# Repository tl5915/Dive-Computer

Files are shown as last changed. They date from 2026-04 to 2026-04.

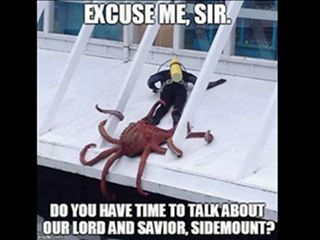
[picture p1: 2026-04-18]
Startup_Image/image.png

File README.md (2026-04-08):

# Dive Computer

Based on the previous [bottom timer project]([https://](https://github.com/tl5915/Bottom-Timer-for-DPV)). Pressure sensor and housing remains the same.

- Add dive computer mode with Bühlmann ZHL-16C algorithm
- Add tilt compensated digital compass with soft and hard iron calibration
- Backlight auto adjustment

## Hardware

- Change MCU from ESP32-C3 to ESP32-S3 (Waveshare ESP32-S3-LCD-1.69)
- Change display from 1.54 inch OLED to 1.69 inch IPS LCD
- Onboard QMI8658 6-axis IMU
- Offboard QMC5883L magnetometer
- Offboard BH1750 light sensor

## Software

- Press onboard button to start compass calibration, rotate in all directions in 60 seconds
- Dive timer start at 1m depth
- Default bottom timer view with digital compass
- Triple tap to switch to dive computer mode:
  
  | Stop | Time | TTS | surfGF |
- In dive computer mode, double tap to change gradient factor to `100/100`

### Decompression model assumptions

- Fixed gradient factor `60/85` (optional overide)
- Close circuit with fixed set point of `1.2`
- Ascent rate 9 m/min
- Sea level 1 atm
- No prior dives
- No helium penalty

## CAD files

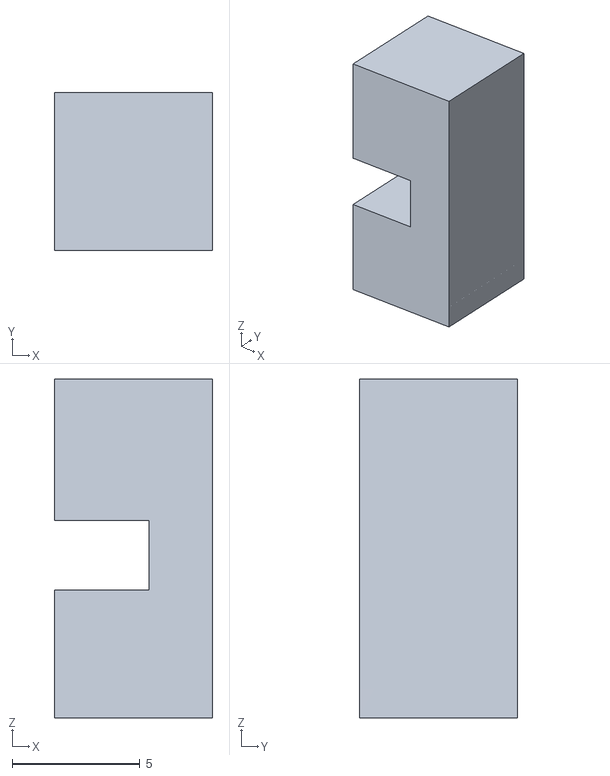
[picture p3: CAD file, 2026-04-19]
STL/Button.stl
6.20 x 6.20 x 13.3

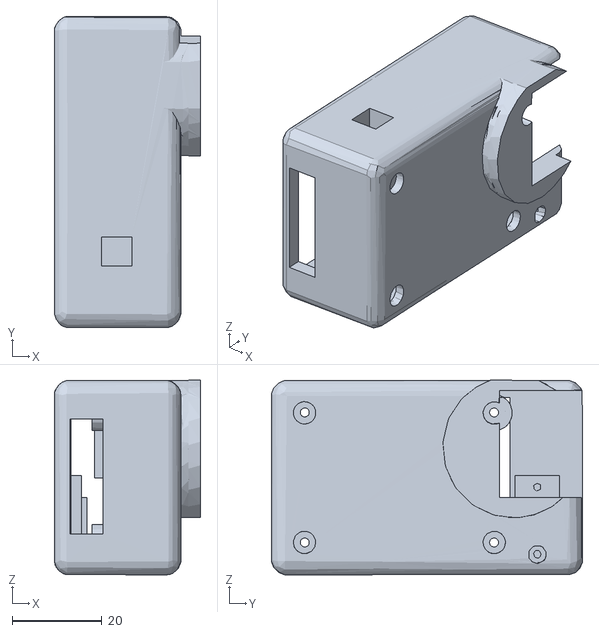
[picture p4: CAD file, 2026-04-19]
STL/Insert_2.stl
32.6 x 69.4 x 43.4

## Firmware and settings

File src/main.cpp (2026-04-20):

#include <Arduino.h>
// Power Management
#include <esp_pm.h>
#include <esp_bt.h>
#include <esp_wifi.h>
#include <esp_sleep.h>
#include <esp_heap_caps.h>
#include <driver/rtc_io.h>
// Peripherals
#include <SPI.h>
#include <Wire.h>
#include <BH1750.h>
#include <MS5837.h>
#include <Adafruit_GFX.h>
#include <Adafruit_ST7789.h>
#include <SensorQMI8658.hpp>
#include <SensorQMC5883P.hpp>
// Data Processing
#include <vector>
#include <WiFi.h>
#include <ZHL16C.h>
#include <SPIFFS.h>
#include <pgmspace.h>
#include <WebServer.h>
#include <Preferences.h>
#include <TJpg_Decoder.h>
#include <Adafruit_AHRS.h>
#include <magnetometer_calibration.h>
// Header Files
#include "demo.h"
#include "image.h"
#include "compass_label.h"

// Pin Definitions
// System
constexpr uint8_t RST_Pin = 0;  // Boot button/ LCD reset
constexpr uint8_t Battery_Pin = 5;  // Battery ADC
// Button
constexpr uint8_t Button_Pin = 9;  // Connect to GND
// I2C
constexpr uint8_t IMU_INT_Pin = 3;  // Internal
constexpr uint8_t QMC_DRDY_Pin = 11;
constexpr uint8_t GND_Pin = 13;  // Grounded
constexpr uint8_t VCC_Pin = 15;
constexpr uint8_t SCL_Pin = 47;  // Fixed
constexpr uint8_t SDA_Pin = 48;  // Fixed
// LCD (internal)
constexpr uint8_t Backlight_Pin = 1;
constexpr uint8_t MOSI_Pin = 38;
constexpr uint8_t SCK_Pin = 39;
constexpr uint8_t MISO_Pin = 40;
constexpr uint8_t SD_CS_Pin = 41;  // SD card CS
constexpr uint8_t DC_Pin = 42;
constexpr uint8_t LCD_CS_Pin = 45;  // LCD CS

// Objects
SPIClass spi(FSPI);
Adafruit_ST7789 display(&spi, LCD_CS_Pin, DC_Pin, RST_Pin);
Preferences prefs;
MS5837 sensor;
BH1750 lightMeter;
SensorQMI8658 qmi;
SensorQMC5883P qmc;
Adafruit_Madgwick ahrs;

// I2C Addresses
constexpr uint8_t QMI8658_I2C_Address = 0x6B;
constexpr uint8_t QMC5883P_I2C_Address = 0x2C;
constexpr uint8_t BH1750_I2C_Address = 0x23;
constexpr uint8_t MS5837_I2C_Address = 0x76;

// LCD Constants
constexpr uint16_t LCD_Width = 320;
constexpr uint16_t LCD_Height = 240;
constexpr uint8_t Low_Battery_Threshold = 10;      // Dim screen at 10%
constexpr uint8_t Critical_Battery_Threshold = 0;  // Auto shut down at 0%
constexpr float Battery_Divider_Ratio = 3.0f;      // 2:1 voltage divider
constexpr float Ambient_Lux_Max = 40000.0f;        // Lux at high backlight
constexpr uint8_t Backlight_Low = 8;               // Low backlight
constexpr uint8_t Backlight_High = 255;            // High backlight
constexpr uint32_t Message_MS = 3000;              // Display messages for 3 seconds
constexpr uint32_t Display_Update_MS = 50;         // Display refresh rate: 20 Hz
constexpr uint32_t Depth_Update_MS = 500;          // Depth sensor and ADC updates: 2 Hz
constexpr uint32_t Deco_Update_MS = 5000;          // Decompression model updates: 0.2 Hz

// Button Constants
constexpr uint32_t Button_Long_MS = 800;          // Long press threshold
constexpr uint32_t Button_Hold_MS = 5000;         // Press and hold threshold
constexpr uint32_t Calibration_Delay_MS = 10000;  // Delay before calibration

// Depth Sensor Constants
constexpr uint16_t Density = 1020;        // EN13319 density
constexpr float MBAR_PER_ATM = 1013.25f;  // mBar per atm
constexpr float Depth_Offset = 0.2f;      // Sea level offset 0.2 m
constexpr float Dive_Start_Depth = 1.0f;  // Start timer at 1 m

// ZHL-16C Constants
constexpr uint8_t GF_Low = 60;    // Gradient factor low
constexpr uint8_t GF_High = 85;   // Gradient factor high
constexpr float Setpoint = 1.2f;  // CCR setpoint

// IMU Offset Constants
constexpr float Accel_Offset_X = 0.0;
constexpr float Accel_Offset_Y = 0.0f;
constexpr float Accel_Offset_Z = 0.0f;
constexpr float Gyro_Offset_X = 0.4791f;
constexpr float Gyro_Offset_Y = 5.7993f;
constexpr float Gyro_Offset_Z = -0.7015f;

// Compass Constants
constexpr float Compass_Offset = 0.0;                        // Compass offset degrees
constexpr float Reference_Field_Gauss = 0.49f;               // UK average magnetic field strength
constexpr float Magnetometer_Lsb_Per_Gauss = 3750.0f;        // QMC5883P at FS_8G: 3750 LSB/Gauss
constexpr uint32_t Compass_Calibration_Duration_MS = 30000;  // 30 seconds for compass calibration
constexpr const char *Compass_NVS_Namespace = "compass";
constexpr const char *Calibration_Valid_Key = "cal_valid";
constexpr const char *Hard_Iron_X_Key = "hi_x";
constexpr const char *Hard_Iron_Y_Key = "hi_y";
constexpr const char *Hard_Iron_Z_Key = "hi_z";
constexpr const char *Soft_Iron_Key = "soft_iron";
constexpr const char *Reference_Mag_Gauss_Key = "ref_gauss";
constexpr const char *Lsb_Per_Gauss_Key = "lsb_gauss";
constexpr const char *Fitted_Field_Lsb_Key = "fit_lsb";
constexpr const char *Settings_NVS_Namespace = "settings";
constexpr const char *Demo_Mode_Key = "demo_mode";

// Default Compass Calibration Matrix
constexpr CompassCalibrationMatrices Default_Compass_Matrices = {
  .hard_iron = {431.913489, 296.874488, 374.476474},
  .soft_iron = {
    0.000330f, 0.000001f, -0.000020f,
    0.000001f, 0.000308f, 0.000008f,
    -0.000020f, 0.000008f, 0.000300f
  },
  .reference_field_gauss = Reference_Field_Gauss,
  .lsb_per_gauss = Magnetometer_Lsb_Per_Gauss,
  .fitted_field_lsb = Reference_Field_Gauss * Magnetometer_Lsb_Per_Gauss,
  .is_valid = true
};

// Battery Percentage Lookup Table
constexpr float Voltage_Table[] = {
    3.27f, 3.61f, 3.69f, 3.71f, 3.73f, 3.75f, 3.77f, 3.79f, 3.80f, 3.82f, 3.84f, 3.85f, 3.87f, 3.91f, 3.95f, 3.98f, 4.02f, 4.08f, 4.11f, 4.15f, 4.20f};
constexpr uint8_t Percentage_Table[] = {
    0, 5, 10, 15, 20, 25, 30, 35, 40, 45, 50, 55, 60, 65, 70, 75, 80, 85, 90, 95, 100};
constexpr size_t Battery_Table_Size = sizeof(Voltage_Table) / sizeof(Voltage_Table[0]);

// SPIFFS JPEG path
constexpr const char *Spiffs_Jpeg_Path = "/image.jpg";

// WiFi AP credentials
constexpr const char *SSID = "DiveComputer";
constexpr const char *Password = "12345678";

// RTOS Variables
TaskHandle_t Display_Task_Handle = nullptr;
TaskHandle_t Sensor_Task_Handle = nullptr;
TaskHandle_t Image_Task_Handle = nullptr;
GFXcanvas16 *Frame_Canvas = nullptr;
uint16_t *Frame_Back_Previous = nullptr;
uint16_t *Frame_Back_Current = nullptr;
uint16_t Render_Width = 0;
uint16_t Render_Height = 0;
size_t Frame_Buffer_Bytes = 0;
bool Frame_Have_Previous = false;
bool Spiffs_Jpeg_Ready = false;

// Modes
bool Demo_Mode = false;
bool ripNtear_Mode = false;

// Dive Variables
float Heading = 0.0f;
float Depth = 0.0f;
int Minutes = 0;
int Seconds = 0;
int Stopwatch_Minutes = 0;
int Stopwatch_Seconds = 0;
uint64_t Timer_Start_MS = 0;
uint64_t Stopwatch_Start_MS = 0;
uint64_t Simulated_Profile_Start_MS = 0;
bool Dive_Timer_Started = false;
bool Stopwatch_Active = false;
bool sensorAvailable = false;

// Battery Variables
float Ambient_Lux = 0.0f;
float Battery_Voltage = 0.0f;
uint8_t Battery_Percentage = 0;
uint8_t Backlight_Level = Backlight_High;

// Press Button Variables
uint8_t Button_Consecutive_Reads = 0;
uint8_t Button_Last_Reading = HIGH;
uint8_t Button_Stable_State = HIGH;
uint64_t Button_Last_Change_MS = 0;
uint64_t Button_Press_Start_MS = 0;
bool Button_Long_Event_Fired = false;
bool Button_Hold_Event_Fired = false;

// Boot Button Variables
uint8_t Boot_Consecutive_Reads = 0;
uint8_t Boot_Last_Reading = HIGH;
uint8_t Boot_Stable_State = HIGH;
uint64_t Boot_Last_Change_MS = 0;
uint64_t Boot_Press_Start_MS = 0;
bool Boot_Long_Event_Fired = false;
bool Boot_Hold_Event_Fired = false;

// Decompression Variables
DecoResult lastDecoResult = {false, 0, 0, 0, 0};
uint64_t Deco_Last_Update_MS = 0;

// Compass Labels
float projectCompassX3D(float x, float centerX, float width) {
  constexpr float Projection_Exponent = 2.1f;
  if (x <= centerX) {
    const float t = constrain(x / centerX, 0.0f, 1.0f);
    return powf(t, Projection_Exponent) * centerX;
  }
  const float rightSpan = width - centerX;
  const float t = constrain((width - x) / rightSpan, 0.0f, 1.0f);
  return (centerX - (powf(t, Projection_Exponent) * centerX)) + centerX;
}
float smoothstep01(float t) {
  t = constrain(t, 0.0f, 1.0f);
  return t * t * (3.0f - (2.0f * t));
}
float compassCenterWeight(float projectedX, float centerX) {
  const float maxDist = centerX;
  const float dist = fabsf(projectedX - centerX);
  const float linearWeight = 1.0f - constrain(dist / maxDist, 0.0f, 1.0f);
  return smoothstep01(linearWeight);
}
void drawScaledXBitmap(Adafruit_GFX &target, int16_t x, int16_t y, uint8_t srcW, uint8_t srcH, const uint8_t *bitmap, float scale, uint16_t color) {
  if (bitmap == nullptr || scale <= 0.0f) return;
  const int16_t dstW = static_cast<int16_t>(srcW * scale + 0.5f);
  const int16_t dstH = static_cast<int16_t>(srcH * scale + 0.5f);
  if (dstW <= 0 || dstH <= 0) return;
  const uint8_t bytesPerRow = static_cast<uint8_t>((srcW + 7) / 8);
  for (int16_t dy = 0; dy < dstH; ++dy) {
    const uint8_t sy = static_cast<uint8_t>((static_cast<int32_t>(dy) * srcH) / dstH);
    for (int16_t dx = 0; dx < dstW; ++dx) {
      const uint8_t sx = static_cast<uint8_t>((static_cast<int32_t>(dx) * srcW) / dstW);
      const uint16_t byteIndex = static_cast<uint16_t>(sy * bytesPerRow + (sx / 8));
      const uint8_t rowByte = pgm_read_byte(bitmap + byteIndex);
      const bool isSet = (rowByte & (1U << (sx & 7))) != 0;
      if (isSet) target.drawPixel(x + dx, y + dy, color);
    }
  }
}

// Compass Calibration Method and Quality
CompassCalibrationMatrices Compass_Matrices = {};
enum class CompassCalibrationMethod : uint8_t {
  None = 0,
  Ellipsoid = 1,
  MinMax = 2,
  Error = 3,
};
CompassCalibrationMethod Last_Calibration_Method = CompassCalibrationMethod::None;
static const char* compassCalibrationMethodText(CompassCalibrationMethod method) {
  switch (method) {
    case CompassCalibrationMethod::Ellipsoid: return "Ellipsoid";
    case CompassCalibrationMethod::MinMax: return "Min/Max";
    case CompassCalibrationMethod::Error: return "Error";
    case CompassCalibrationMethod::None:
    default: return "None";
  }
}
CompassCalibrationQuality Last_Calibration_Quality = {};
enum class CalibrationFailReason : uint8_t {
  None = 0,
  TooFewSamples,
  FitFailed,
  ApplyFailed,
  InvalidQuality,
};
CalibrationFailReason Last_Calibration_Fail_Reason = CalibrationFailReason::None;
size_t Last_Calibration_Sample_Count = 0;
uint32_t Last_Calibration_Elapsed_MS = 0;
static const char* calibrationFailReasonText(CalibrationFailReason reason) {
  switch (reason) {
    case CalibrationFailReason::TooFewSamples: return "Too few samples";
    case CalibrationFailReason::FitFailed: return "Fit failed";
    case CalibrationFailReason::ApplyFailed: return "Apply failed";
    case CalibrationFailReason::InvalidQuality: return "Invalid quality";
    case CalibrationFailReason::None:
    default: return "None";
  }
}

// Press Button State
enum class PressButtonEvent : uint8_t {
  None = 0,
  ShortPress,
  LongPress,
  HoldPress,
};
PressButtonEvent checkButton(uint64_t nowMS) {
  const uint8_t reading = static_cast<uint8_t>(digitalRead(Button_Pin));
  PressButtonEvent event = PressButtonEvent::None;
  if (reading == Button_Stable_State) {
    Button_Consecutive_Reads = 0;
  } else {
    if (reading == Button_Last_Reading) {
      if (Button_Consecutive_Reads < UINT8_MAX) Button_Consecutive_Reads++;
    } else {
      Button_Consecutive_Reads = 1;
    }
    Button_Last_Reading = reading;
    if (Button_Consecutive_Reads >= 2) {
      Button_Consecutive_Reads = 0;
      Button_Stable_State = reading;
      if (Button_Stable_State == LOW) {
        Button_Press_Start_MS = nowMS;
        Button_Long_Event_Fired = false;
        Button_Hold_Event_Fired = false;
      } else {
        const uint64_t heldMS = nowMS - Button_Press_Start_MS;
        if (!Button_Long_Event_Fired && heldMS < Button_Long_MS) {
          event = PressButtonEvent::ShortPress;
        } else if (!Button_Hold_Event_Fired && heldMS >= Button_Long_MS) {
          Button_Long_Event_Fired = true;
          event = PressButtonEvent::LongPress;
        }
      }
    }
  }
  if (Button_Stable_State == LOW) {
    const uint64_t heldMS = nowMS - Button_Press_Start_MS;
    if (!Button_Hold_Event_Fired && heldMS >= Button_Hold_MS) {
      Button_Hold_Event_Fired = true;
      event = PressButtonEvent::HoldPress;
    }
  }
  return event;
}

// Boot Button State
enum class BootButtonEvent : uint8_t {
  None = 0,
  ShortPress,
  LongPress,
  HoldPress,
};
BootButtonEvent checkBootButton(uint64_t nowMS) {
  const uint8_t reading = static_cast<uint8_t>(digitalRead(RST_Pin));
  BootButtonEvent event = BootButtonEvent::None;
  if (reading == Boot_Stable_State) {
    Boot_Consecutive_Reads = 0;
  } else {
    if (reading == Boot_Last_Reading) {
      if (Boot_Consecutive_Reads < UINT8_MAX) Boot_Consecutive_Reads++;
    } else {
      Boot_Consecutive_Reads = 1;
    }
    Boot_Last_Reading = reading;
    if (Boot_Consecutive_Reads >= 2) {
      Boot_Consecutive_Reads = 0;
      Boot_Stable_State = reading;
      if (Boot_Stable_State == LOW) {
        Boot_Press_Start_MS = nowMS;
        Boot_Long_Event_Fired = false;
        Boot_Hold_Event_Fired = false;
      } else {
        const uint64_t heldMS = nowMS - Boot_Press_Start_MS;
        if (!Boot_Long_Event_Fired && heldMS < Button_Long_MS) {
          event = BootButtonEvent::ShortPress;
        } else if (!Boot_Long_Event_Fired && heldMS >= Button_Long_MS) {
          Boot_Long_Event_Fired = true;
          event = BootButtonEvent::LongPress;
        }
      }
    }
  }
  if (Boot_Stable_State == LOW) {
    const uint64_t heldMS = nowMS - Boot_Press_Start_MS;
    if (!Boot_Hold_Event_Fired && heldMS >= Button_Hold_MS) {
      Boot_Hold_Event_Fired = true;
      event = BootButtonEvent::HoldPress;
    }
  }
  return event;
}

// Frame Buffer Management
bool initFrameBuffers() {
  Render_Width = static_cast<uint16_t>(display.width());
  Render_Height = static_cast<uint16_t>(display.height());
  Frame_Buffer_Bytes = static_cast<size_t>(Render_Width) * static_cast<size_t>(Render_Height) * sizeof(uint16_t);
  Frame_Canvas = new GFXcanvas16(Render_Width, Render_Height);
  if (Frame_Canvas == nullptr || Frame_Canvas->getBuffer() == nullptr) return false;
  Frame_Back_Previous = static_cast<uint16_t *>(heap_caps_malloc(Frame_Buffer_Bytes, MALLOC_CAP_SPIRAM | MALLOC_CAP_8BIT));
  Frame_Back_Current = static_cast<uint16_t *>(heap_caps_malloc(Frame_Buffer_Bytes, MALLOC_CAP_SPIRAM | MALLOC_CAP_8BIT));
  if (Frame_Back_Previous == nullptr || Frame_Back_Current == nullptr) return false;
  memset(Frame_Back_Previous, 0, Frame_Buffer_Bytes);
  memset(Frame_Back_Current, 0, Frame_Buffer_Bytes);
  Frame_Have_Previous = false;
  return true;
}

// Flush from PSRAM
void flushDirtyRectFromPSRAM() {
  if (Frame_Back_Previous == nullptr || Frame_Back_Current == nullptr || Render_Width == 0 || Render_Height == 0) return;
  uint16_t dirtyX0 = Render_Width;
  uint16_t dirtyY0 = Render_Height;
  uint16_t dirtyX1 = 0;
  uint16_t dirtyY1 = 0;
  bool hasDirty = !Frame_Have_Previous;
  if (!hasDirty) {
    for (uint16_t y = 0; y < Render_Height; ++y) {
      const size_t rowOffset = static_cast<size_t>(y) * static_cast<size_t>(Render_Width);
      int16_t left = -1;
      int16_t right = -1;
      for (uint16_t x = 0; x < Render_Width; ++x) {
        const size_t idx = rowOffset + static_cast<size_t>(x);
        if (Frame_Back_Current[idx] != Frame_Back_Previous[idx]) {
          if (left < 0) left = static_cast<int16_t>(x);
          right = static_cast<int16_t>(x);
        }
      }
      if (left >= 0) {
        hasDirty = true;
        if (y < dirtyY0) dirtyY0 = y;
        if (y > dirtyY1) dirtyY1 = y;
        if (static_cast<uint16_t>(left) < dirtyX0) dirtyX0 = static_cast<uint16_t>(left);
        if (static_cast<uint16_t>(right) > dirtyX1) dirtyX1 = static_cast<uint16_t>(right);
      }
    }
  }
  if (hasDirty) {
    if (!Frame_Have_Previous) {
      dirtyX0 = 0;
      dirtyY0 = 0;
      dirtyX1 = static_cast<uint16_t>(Render_Width - 1);
      dirtyY1 = static_cast<uint16_t>(Render_Height - 1);
    }
    const uint16_t dirtyW = static_cast<uint16_t>(dirtyX1 - dirtyX0 + 1);
    const uint16_t dirtyH = static_cast<uint16_t>(dirtyY1 - dirtyY0 + 1);
    display.startWrite();
    display.setAddrWindow(dirtyX0, dirtyY0, dirtyW, dirtyH);
    for (uint16_t row = 0; row < dirtyH; ++row) {
      const uint16_t srcY = static_cast<uint16_t>(dirtyY0 + row);
      uint16_t *rowPtr = &Frame_Back_Current[(static_cast<size_t>(srcY) * Render_Width) + dirtyX0];
      display.writePixels(rowPtr, dirtyW, true, false);
    }
    display.endWrite();
  }
  uint16_t *tmp = Frame_Back_Previous;
  Frame_Back_Previous = Frame_Back_Current;
  Frame_Back_Current = tmp;
  Frame_Have_Previous = true;
}

// Load Compass Calibration Values
bool loadCompassCalibrationFromNVS() {
  if (!prefs.begin(Compass_NVS_Namespace, true)) return false;
  const bool valid = prefs.getBool(Calibration_Valid_Key, false);
  if (!valid || !prefs.isKey(Hard_Iron_X_Key)) {
    prefs.end();
    return false;
  }
  CompassCalibrationMatrices loaded = {};
  loaded.hard_iron[0] = prefs.getFloat(Hard_Iron_X_Key, 0.0f);
  loaded.hard_iron[1] = prefs.getFloat(Hard_Iron_Y_Key, 0.0f);
  loaded.hard_iron[2] = prefs.getFloat(Hard_Iron_Z_Key, 0.0f);
  loaded.reference_field_gauss = prefs.getFloat(Reference_Mag_Gauss_Key, Reference_Field_Gauss);
  loaded.lsb_per_gauss = prefs.getFloat(Lsb_Per_Gauss_Key, Magnetometer_Lsb_Per_Gauss);
  loaded.fitted_field_lsb = prefs.getFloat(Fitted_Field_Lsb_Key, loaded.reference_field_gauss * loaded.lsb_per_gauss);
  const size_t soft_iron_size = prefs.getBytesLength(Soft_Iron_Key);
  if (soft_iron_size != (9U * sizeof(float))) {
    prefs.end();
    return false;
  }
  prefs.getBytes(Soft_Iron_Key, loaded.soft_iron, soft_iron_size);
  loaded.is_valid = true;
  prefs.end();
  compassConfigureReferenceField(loaded.reference_field_gauss, loaded.lsb_per_gauss);
  Compass_Matrices = loaded;
  return compassSetCalibrationMatrices(&Compass_Matrices);
}

// Save Compass Calibration Values
void saveCompassCalibrationToNVS(const CompassCalibrationMatrices& matrices) {
  if (!prefs.begin(Compass_NVS_Namespace, false)) return;
  prefs.putFloat(Hard_Iron_X_Key, matrices.hard_iron[0]);
  prefs.putFloat(Hard_Iron_Y_Key, matrices.hard_iron[1]);
  prefs.putFloat(Hard_Iron_Z_Key, matrices.hard_iron[2]);
  prefs.putBytes(Soft_Iron_Key, matrices.soft_iron, 9U * sizeof(float));
  prefs.putFloat(Reference_Mag_Gauss_Key, matrices.reference_field_gauss);
  prefs.putFloat(Lsb_Per_Gauss_Key, matrices.lsb_per_gauss);
  prefs.putFloat(Fitted_Field_Lsb_Key, matrices.fitted_field_lsb);
  prefs.putBool(Calibration_Valid_Key, matrices.is_valid);
  prefs.end();
}

// Load Demo Mode State
void loadDemoMode() {
  if (prefs.begin(Settings_NVS_Namespace, true)) {
    Demo_Mode = prefs.getBool(Demo_Mode_Key, false);
    prefs.end();
  }
}

// Save Demo Mode State
void saveDemoMode() {
  prefs.begin(Settings_NVS_Namespace, false);
  prefs.putBool(Demo_Mode_Key, Demo_Mode);
  prefs.end();
}

// Display Centre Text 
void drawCentreText(const char *text, int16_t y, uint8_t font, uint16_t colour) {
  int16_t x1 = 0;
  int16_t y1 = 0;
  uint16_t w = 0;
  uint16_t h = 0;
  display.setTextSize(font);
  display.setTextWrap(false);
  display.getTextBounds(text, 0, y, &x1, &y1, &w, &h);
  const int16_t x = ((display.width() - static_cast<int16_t>(w)) / 2) - x1;
  display.setCursor(x, y);
  display.setTextColor(colour);
  display.print(text);
}

// Display Column-Centred Text
void drawColCentreText(Adafruit_GFX &target, const char *text, int16_t colX, int16_t colW, int16_t y, uint8_t font, uint16_t colour) {
  int16_t x1 = 0, y1 = 0;
  uint16_t w = 0, h = 0;
  target.setTextSize(font);
  target.setTextWrap(false);
  target.getTextBounds(text, 0, y, &x1, &y1, &w, &h);
  const int16_t x = colX + ((colW - static_cast<int16_t>(w)) / 2) - x1;
  target.setCursor(x, y);
  target.setTextColor(colour, ST77XX_BLACK);
  target.print(text);
}

// Backlight Level
uint8_t ambientBacklightLevel(float lux) {
  if (lux <= 0.0f) return Backlight_Low;
  float normalised = log10f(lux + 1.0f) / log10f(Ambient_Lux_Max + 1.0f);
  if (normalised < 0.0f) normalised = 0.0f;
  if (normalised > 1.0f) normalised = 1.0f;
  return static_cast<uint8_t>(Backlight_Low + normalised * static_cast<float>(Backlight_High - Backlight_Low));
}

// Read Gyroscope and Map to Body Frame
void readGyroTransformed(float out_gyro[3]) {
  float gx = 0.0f;
  float gy = 0.0f;
  float gz = 0.0f;
  qmi.getGyroscope(gx, gy, gz);
  gx -= Gyro_Offset_X;
  gy -= Gyro_Offset_Y;
  gz -= Gyro_Offset_Z;
  out_gyro[0] = gx;   // Right = QMI_X
  out_gyro[1] = -gy;  // Down = -QMI_Y
  out_gyro[2] = -gz;  // Forward = -QMI_Z
}

// Read Accelerometer and Map to Body Frame
void readAccelTransformed(float out_accel[3]) {
  float ax = 0.0f;
  float ay = 0.0f;
  float az = 0.0f;
  qmi.getAccelerometer(ax, ay, az);
  ax -= Accel_Offset_X;
  ay -= Accel_Offset_Y;
  az -= Accel_Offset_Z;
  out_accel[0] = ax;   // Right = QMI_X
  out_accel[1] = -ay;  // Down = -QMI_Y
  out_accel[2] = -az;  // Forward = QMI_Z
}

// Read Magnetometer and Map to Body Frame
void readMagTransformed(float out_mag[3]) {
  MagnetometerData mag_data = {};
  qmc.readData(mag_data);
  float mx = static_cast<float>(mag_data.raw.x);
  float my = static_cast<float>(mag_data.raw.y);
  float mz = static_cast<float>(mag_data.raw.z);
  out_mag[0] = -mx;  // Right = -QMC_X
  out_mag[1] = -my;  // Down = -QMC_Y
  out_mag[2] = -mz;  // Forward = -QMC_Z
}
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
void loop() {
  vTaskDelay(pdMS_TO_TICKS(1000));
}

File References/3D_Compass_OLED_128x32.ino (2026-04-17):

// simple project using Arduino UNO and 128x32 SSD1306 IIC OLED Display to show compass (driven by potentiometer)

// created by upir, 2024
// youtube channel: https://www.youtube.com/upir_upir

// YOUTUBE VIDEO: https://youtu.be/q1HzAcj0n7Y
// SOURCE FILES: https://github.com/upiir/arduino_oled_3d_compass
// WOKWI PROJECT: https://wokwi.com/projects/385987811439126529

// Links from the video:
// starting wokwi project: https://wokwi.com/projects/371852029526395905
// 10K Potentiometer: https://s.click.aliexpress.com/e/_Dk1WFoV
// 128x64 SSD1306 OLED Display 1.54": https://s.click.aliexpress.com/e/_DCYdWXb
// 128x64 SSD1306 OLED Display 0.96": https://s.click.aliexpress.com/e/_DCKdvnh
// 128x64 SSD1306 OLED Display 2.42": https://s.click.aliexpress.com/e/_DFdMoTh
// Breadboard wires: https://s.click.aliexpress.com/e/_Dkbngin
// Arduino UNO: https://s.click.aliexpress.com/e/_AXDw1h
// Arduino breadboard prototyping shield: https://s.click.aliexpress.com/e/_ApbCwx
// Image2cpp (convert array to image): https://javl.github.io/image2cpp/
// Photopea (online graphics editor like Photoshop): https://www.photopea.com/
// arrays of strings: https://www.arduino.cc/reference/en/language/variables/data-types/string/
// 128x64 display initialization: https://github.com/olikraus/u8g2/wiki/u8g2setupcpp#ssd1306-128x32_univision
// used u8g2 font: https://github.com/olikraus/u8g2/wiki/fntgrpu8g#squeezed_b7

// Related videos with Arduino UNO and OLED screen:
// Image to OLED in 60 seconds - https://www.youtube.com/watch?v=Lw0Aaoo3YSY
// Arduino + OLED displays: https://www.youtube.com/playlist?list=PLjQRaMdk7pBZ1UV3IL5ol8Qc7R9k-kwXA

#include <Arduino.h>
#include <U8g2lib.h> // u8g2 library is used to draw graphics on the OLED display
#include <Wire.h> // library required for IIC communication

//U8G2_SSD1306_128X64_NONAME_F_HW_I2C u8g2(U8G2_R0, /* reset=*/ U8X8_PIN_NONE); // initialization for the 128x64px OLED display
U8G2_SSD1306_128X32_UNIVISION_F_HW_I2C u8g2(U8G2_R0, /* reset=*/ U8X8_PIN_NONE); // initialization for the 128x32px OLED display, [full framebuffer, size = 512 bytes]


// two bubble images were drawn in Photopea and arrays were created using the image2cpp website

// 'img_bubble_fill', 26x13px
const unsigned char epd_bitmap_img_bubble_fill [] PROGMEM = {
  0xfc, 0xff, 0xff, 0x00, 0xfe, 0xff, 0xff, 0x01, 0xfe, 0xff, 0xff, 0x01, 0xfe, 0xff, 0xff, 0x01,
  0xfe, 0xff, 0xff, 0x01, 0xfe, 0xff, 0xff, 0x01, 0xfe, 0xff, 0xff, 0x01, 0xfe, 0xff, 0xff, 0x01,
  0xfc, 0xff, 0xff, 0x00, 0x00, 0xfc, 0x00, 0x00, 0x00, 0x78, 0x00, 0x00, 0x00, 0x30, 0x00, 0x00,
  0x00, 0x00, 0x00, 0x00
};
// 'img_bubble_outline', 26x13px
const unsigned char epd_bitmap_img_bubble_outline [] PROGMEM = {
  0xfe, 0xff, 0xff, 0x01, 0xff, 0xff, 0xff, 0x03, 0xff, 0xff, 0xff, 0x03, 0xff, 0xff, 0xff, 0x03,
  0xff, 0xff, 0xff, 0x03, 0xff, 0xff, 0xff, 0x03, 0xff, 0xff, 0xff, 0x03, 0xff, 0xff, 0xff, 0x03,
  0xfe, 0xff, 0xff, 0x01, 0xfc, 0xff, 0xff, 0x00, 0x00, 0xfc, 0x00, 0x00, 0x00, 0x78, 0x00, 0x00,
  0x00, 0x30, 0x00, 0x00
};


// scaled labels as images

// '000_letter_n_0', 26x12px
const unsigned char epd_bitmap_000_letter_n_0 [] PROGMEM = {
  0x00, 0x48, 0x00, 0x00, 0x00, 0x48, 0x00, 0x00, 0x00, 0x58, 0x00, 0x00, 0x00, 0x58, 0x00, 0x00,
  0x00, 0x58, 0x00, 0x00, 0x00, 0x58, 0x00, 0x00, 0x00, 0x68, 0x00, 0x00, 0x00, 0x68, 0x00, 0x00,
  0x00, 0x68, 0x00, 0x00, 0x00, 0x68, 0x00, 0x00, 0x00, 0x48, 0x00, 0x00, 0x00, 0x48, 0x00, 0x00
};
// '000_letter_n_1', 26x12px
const unsigned char epd_bitmap_000_letter_n_1 [] PROGMEM = {
  0x00, 0x88, 0x00, 0x00, 0x00, 0x98, 0x00, 0x00, 0x00, 0x98, 0x00, 0x00, 0x00, 0x98, 0x00, 0x00,
  0x00, 0x98, 0x00, 0x00, 0x00, 0xa8, 0x00, 0x00, 0x00, 0xa8, 0x00, 0x00, 0x00, 0xa8, 0x00, 0x00,
  0x00, 0xc8, 0x00, 0x00, 0x00, 0xc8, 0x00, 0x00, 0x00, 0xc8, 0x00, 0x00, 0x00, 0x88, 0x00, 0x00
};
// '000_letter_n_2', 26x12px
const unsigned char epd_bitmap_000_letter_n_2 [] PROGMEM = {
  0x00, 0x8c, 0x01, 0x00, 0x00, 0x9c, 0x01, 0x00, 0x00, 0x9c, 0x01, 0x00, 0x00, 0xbc, 0x01, 0x00,
  0x00, 0xbc, 0x01, 0x00, 0x00, 0xbc, 0x01, 0x00, 0x00, 0xec, 0x01, 0x00, 0x00, 0xec, 0x01, 0x00,
  0x00, 0xec, 0x01, 0x00, 0x00, 0xcc, 0x01, 0x00, 0x00, 0xcc, 0x01, 0x00, 0x00, 0x8c, 0x01, 0x00
};
// '000_letter_n_3', 26x12px
const unsigned char epd_bitmap_000_letter_n_3 [] PROGMEM = {
  0x00, 0x03, 0x03, 0x00, 0x00, 0x07, 0x03, 0x00, 0x00, 0x0f, 0x03, 0x00, 0x00, 0x0f, 0x03, 0x00,
  0x00, 0x1b, 0x03, 0x00, 0x00, 0x33, 0x03, 0x00, 0x00, 0x33, 0x03, 0x00, 0x00, 0x63, 0x03, 0x00,
  0x00, 0xc3, 0x03, 0x00, 0x00, 0xc3, 0x03, 0x00, 0x00, 0x83, 0x03, 0x00, 0x00, 0x03, 0x03, 0x00
};
// '045_letter_ne_0', 26x12px
const unsigned char epd_bitmap_045_letter_ne_0 [] PROGMEM = {
  0x00, 0xd2, 0x01, 0x00, 0x00, 0xd2, 0x01, 0x00, 0x00, 0x56, 0x00, 0x00, 0x00, 0x56, 0x00, 0x00,
  0x00, 0x56, 0x00, 0x00, 0x00, 0xd6, 0x01, 0x00, 0x00, 0xda, 0x01, 0x00, 0x00, 0x5a, 0x00, 0x00,
  0x00, 0x5a, 0x00, 0x00, 0x00, 0x5a, 0x00, 0x00, 0x00, 0xd2, 0x01, 0x00, 0x00, 0xd2, 0x01, 0x00
};
// '045_letter_ne_1', 26x12px
const unsigned char epd_bitmap_045_letter_ne_1 [] PROGMEM = {
  0x00, 0xd1, 0x03, 0x00, 0x00, 0xd3, 0x03, 0x00, 0x00, 0x53, 0x00, 0x00, 0x00, 0x53, 0x00, 0x00,
  0x00, 0x53, 0x00, 0x00, 0x00, 0xd5, 0x03, 0x00, 0x00, 0xd5, 0x03, 0x00, 0x00, 0x55, 0x00, 0x00,
  0x00, 0x59, 0x00, 0x00, 0x00, 0x59, 0x00, 0x00, 0x00, 0xd9, 0x03, 0x00, 0x00, 0xd1, 0x03, 0x00
};
// '045_letter_ne_2', 26x12px
const unsigned char epd_bitmap_045_letter_ne_2 [] PROGMEM = {
  0xc0, 0xd8, 0x0f, 0x00, 0xc0, 0xd9, 0x0f, 0x00, 0xc0, 0xd9, 0x00, 0x00, 0xc0, 0xdb, 0x00, 0x00,
  0xc0, 0xdb, 0x00, 0x00, 0xc0, 0xdb, 0x0f, 0x00, 0xc0, 0xde, 0x0f, 0x00, 0xc0, 0xde, 0x00, 0x00,
  0xc0, 0xde, 0x00, 0x00, 0xc0, 0xdc, 0x00, 0x00, 0xc0, 0xdc, 0x0f, 0x00, 0xc0, 0xd8, 0x0f, 0x00
};
// '045_letter_ne_3', 26x12px
const unsigned char epd_bitmap_045_letter_ne_3 [] PROGMEM = {
  0x18, 0xd8, 0x7f, 0x00, 0x38, 0xd8, 0x7f, 0x00, 0x78, 0xd8, 0x00, 0x00, 0x78, 0xd8, 0x00, 0x00,
  0xd8, 0xd8, 0x00, 0x00, 0x98, 0xd9, 0x7f, 0x00, 0x98, 0xd9, 0x7f, 0x00, 0x18, 0xdb, 0x00, 0x00,
  0x18, 0xde, 0x00, 0x00, 0x18, 0xde, 0x00, 0x00, 0x18, 0xdc, 0x7f, 0x00, 0x18, 0xd8, 0x7f, 0x00
};
// '090_letter_e_0', 26x12px
const unsigned char epd_bitmap_090_letter_e_0 [] PROGMEM = {
  0x00, 0x38, 0x00, 0x00, 0x00, 0x38, 0x00, 0x00, 0x00, 0x08, 0x00, 0x00, 0x00, 0x08, 0x00, 0x00,
  0x00, 0x08, 0x00, 0x00, 0x00, 0x38, 0x00, 0x00, 0x00, 0x38, 0x00, 0x00, 0x00, 0x08, 0x00, 0x00,
  0x00, 0x08, 0x00, 0x00, 0x00, 0x08, 0x00, 0x00, 0x00, 0x38, 0x00, 0x00, 0x00, 0x38, 0x00, 0x00
};
// '090_letter_e_1', 26x12px
const unsigned char epd_bitmap_090_letter_e_1 [] PROGMEM = {
  0x00, 0x78, 0x00, 0x00, 0x00, 0x78, 0x00, 0x00, 0x00, 0x08, 0x00, 0x00, 0x00, 0x08, 0x00, 0x00,
  0x00, 0x08, 0x00, 0x00, 0x00, 0x78, 0x00, 0x00, 0x00, 0x78, 0x00, 0x00, 0x00, 0x08, 0x00, 0x00,
  0x00, 0x08, 0x00, 0x00, 0x00, 0x08, 0x00, 0x00, 0x00, 0x78, 0x00, 0x00, 0x00, 0x78, 0x00, 0x00
};
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

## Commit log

2026-04-06 Dive computer mode
    [partitions.csv]
2026-04-06 Combine deco update/compute timer; Add loop usage.
2026-04-07 Ellipsoid calibration for magnetometer
2026-04-07 Put magnetometer calibration functions in library
2026-04-07 Change to public magnetometer_calibration library
2026-04-08 Add ellpisoid calibration quality metric
2026-04-08 Update magnetometer calibration library version
2026-04-08 Put MS5837 on seperate I2C bus Use DRDY pin for QMC5883L data ready check
2026-04-09 PSRAM double frame buffering and power management
2026-04-10 Stable version on hardware. Still problem with magnetometer reading.
    [main.cpp]
2026-04-10 Fix heading direction coordinate convention
    [main.cpp]
2026-04-10 Change to magnetometer calibration library v1.2.0
2026-04-10 Restart after Compass Calibration
2026-04-10 Change calibration button to boot button; Use user button for power on with battery; Make compass calibration blocking; Change magnetometer full scale range to 8G; Increase magnetometer ODR and incre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
2026-04-10 Add board schematics to reference folder. Pull down buzzer pin to prevent heating.
    [partitions.csv]
2026-04-11 Calibration at 100 Hz for 120 seconds.
2026-04-12 IMU axis rearrangement
2026-04-13 Change heading calculation to AHRS fusion; Change input to button press for power and functions;
2026-04-13 Change IMU sample rate
2026-04-13 Add magnetometer data export build file
2026-04-13 Accelerometer and gyroscope calibration data added; Default magnetometer calibration added.
2026-04-13 add calibration calculation file
    [calculation.xlsx]
2026-04-15 Stable version v1.0.0
    [calculation.xlsx]
2026-04-15 Add charging scree, add STL files, v1.0.1
    [Button.stl, Dive_Computer_Insert.stl]
2026-04-15 magnetometer_calibration library update to v1.3.0
2026-04-16 Add timer function; merge demo profile into main.cpp
2026-04-16 Buzzer change to single tone
    [main.cpp]
2026-04-16 Buzzer function finalised, added demo mode toggle. Stable version v1.1.0
    [buzzer.cpp, main.cpp]
2026-04-17 Demo mode toggle bug fixed. v1.3.1
    [main.cpp]
2026-04-18 Change from 1.69 to 2.0 inch LCD board. v2.0.0
    [partitions.csv]
2026-04-18 Change pin assignments. v2.1.1
2026-04-19 Change pin assignments; Ensure power pin low in deep sleep; v2.1.2
2026-04-19 Reduce compass reading to 20Hz; Non-blocking image display; v2.1.4
2026-04-19 Sync setting of IMU_Calibration.cpp. v2.1.4
    [Button.stl, Dive_Computer_Insert.stl, Insert_2.stl]
2026-04-20 deep sleep pin hold
